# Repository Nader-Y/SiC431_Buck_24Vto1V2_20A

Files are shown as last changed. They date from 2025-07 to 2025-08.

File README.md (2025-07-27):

# SiC431 Buck Converter – 12/24 V to 1.2 V / 20 A

This project implements a high-efficiency synchronous buck converter using the Vishay SiC431 controller. It is designed to step down 12 V or 24 V input to a regulated 1.2 V output, capable of supplying up to 20 A continuous current. The design is intended for powering high-performance digital loads such as CPUs or FPGAs, with tight voltage ripple and thermal constraints.

## Specifications

 - Input Voltage: 4.5 V (min), 12 V (typ), 24 V (max)  

 - Output Voltage: 1.2 V  

 - Load Current: Up to 20 A continuous  

 - Switching Frequency: 500 kHz  

 - Output Voltage Ripple Target: ≤1%  

 - Efficiency: 88% at full load  

 - Control IC: Vishay SiC431  

 - Topology: Synchronous Buck Converter

## Intended Use

This converter is intended for high-current point-of-load applications such as:

 - Intel Xeon processor core power supply

 - FPGA and SoC internal power rails

 - Embedded computing systems requiring precise low-voltage power

## Evaluation Update

# 

Following a detailed evaluation of alternate designs, the difference in efficiency values—as discussed in the feasibility assessment—was found to be insignificant for the intended application. This conclusion is documented in: `00_Design_Calculations/Feasibility Report.doc`

## References

 - Vishay SiC431 Datasheet  

 - Intel Xeon 6 Platform Power Guidelines  

 - Capacitor vendor datasheets (Murata, Panasonic)

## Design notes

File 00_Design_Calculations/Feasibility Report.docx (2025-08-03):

# Feasibility Report: Upgrading from SiC431 (87% Efficiency) to SiC450 (95% Efficiency)

Assuming 24/7 Continuous Operation

## 1. Introduction

This report evaluates the technical and economic feasibility of upgrading a buck converter design from using the SiC431 IC (87% efficiency) to the SiC450 IC (95% efficiency). The application assumes a 1.2 V, 20 A output with continuous 24/7 operation. The analysis includes energy losses, thermal benefits, and return on investment based on IC price differences.

## 2. System and Operation Assumptions

Parameter | Value
Output voltage Vout | 1.2 V
Output current Iout | 20 A
Input voltage Vin | 12 V
Efficiency (SiC431) | 87% (0.87)
Efficiency (SiC450) | 95% (0.95)
Operation time | 24 hours/day
Operation days per year | 365 days/year
Switching frequency | 500 kHz

## 3. Power Calculations

### 3.1. Output Power

Pout=Vout⋅Iout=1.2⋅20=24 W

### 3.2. Input Power and Losses

Metric | SiC431 | SiC450
Input Power | 24/0.87≈27.59 W | 24/0.95≈25.26 W
Power Loss | 3.59 W | 1.26 W
Power Saved | — | 2.33 W less

### 3.3. Daily and Annual Energy Loss

Metric | SiC431 | SiC450
Daily Loss (Wh) | 3.59⋅24= 86.16W | 1.26⋅24=30.24
Annual Loss (Wh) | 86.16⋅365=31,436.4 | 30.24⋅365=11,037.6
Annual Loss (kWh) | 31.44 kW | 11.04 kW
Annual Energy Saved | — | 20.4 kW

### 3.4. Cost Savings (Assuming €0.30/kWh)

Annual savings per unit=20.4⋅0.30=€6.12

## 4. Thermal Considerations

- The SiC450 reduces power loss by 2.33 W.
- This can lower PCB surface temperatures, reduce cooling requirements, and potentially improve product reliability and lifespan.
- For dense or passively cooled systems, the thermal advantage may justify the upgrade independently of energy cost.

## 5. Return on Investment

Item | Value
Typical price difference (SiC450 – SiC431) | ~6.5€–2.5€
Annual energy savings | ~6.12 € per unit
Simple payback time | 7–8 months
Net gain after 1 year | ~2.12€
Net gain after 3 years | ~14.36€ (per unit)

The higher efficiency of the SiC450 becomes financially favorable in less than one year under 24/7 operation.

## 6. Summary Table

Metric | SiC431 | SiC450 | Gain (SiC450 – SiC431)
Efficiency | 87% | 95% | +8%
Input Power | 27.59 W | 25.26 W | –2.33 W
Power Loss | 3.59 W | 1.26 W | –2.33 W
Yearly Energy Waste | 31.44 kWh | 11.04 kWh | –20.4 kWh
Annual Energy Cost (at €0.30) | 9.43€ | 3.31€ | 6.12 € saved
Thermal Load | High | Lower | notable reduction
Payback Period | — | ~7-8 months | —

While the SiC450 offers higher efficiency and reduced thermal loss, it comes at a slightly higher component cost—typically around €4.00 more than the SiC431. However, under continuous 24/7 operation, the annual energy savings (~€6.12 per unit) recover this cost in approximately 7.8 months. This results in a net gain of about €2.12 after one year, and ~€14.36 after three years. Therefore, even after factoring in the IC price difference, the upgrade remains financially and technically beneficial for systems with long operating hours or thermal constraints.

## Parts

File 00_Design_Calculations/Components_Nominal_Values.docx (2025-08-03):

Design Calculations & Nominal Component Selection for Buck Converter Using SiC431

This buck converter is designed to deliver a stable and efficient 3.3 V power rail suitable for powering Intel® Xeon® processors, which require precise and reliable voltage supplies for optimal operation. The wide input voltage range from 4.5 V to 24 V allows compatibility with various power sources commonly found in server and enterprise environments where Xeon processors are deployed. Supporting a high load current of up to 20 A ensures the converter can meet the substantial power demands of multi-core Xeon CPUs during peak processing loads. The 500 kHz switching frequency balances efficiency and output ripple, aligning with the stringent voltage regulation and noise immunity requirements typical of Intel® Xeon® voltage regulator modules (VRMs), thereby ensuring processor stability, performance, and longevity in demanding applications.

### 1. Design Parameters

- VIN = 12 V
- VOUT = 1.2 V
- ETA=0.88(efficiency)
- IOUT = 20 A
- IL_(ripple) =4A (20% of IOUT)
- FSW = 500KHZ
- VCIN_P =0.5V(peak to peak input ripple)

### 2. Duty Cycle

### D=(V_(OUT))/(η⋅V_(IN))

D=1.2/(0.88⋅12)=1.2/10.56≈0.1136

### 3. Inductor Value

L=((V_(IN) -V_(OUT) )⋅D)/(ΔI_L ⋅f_(SW))

L=((12-1.2)⋅0.1136)/(0.2*20⋅500000)=(10.8⋅0.1136)/2000000≈1.2269/2000000

L ≈ 560 nH

### Ripple Current Formula:

ΔIL=((V_(in) -V_(out) )⋅D)/(L⋅f_(SW))

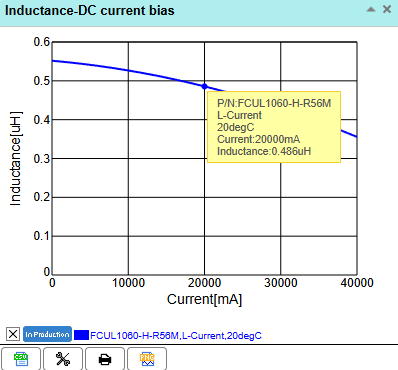
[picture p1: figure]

### Ripple Percentage:

Reducing inductance from 560 nH → 484 nH causes:

- Ripple current to increase from 3.86 A → 4.46 A
- Ripple from 19.3% → 22.3%

This is still within acceptable range, but we will:

- Need slightly more output capacitance
- See slightly higher voltage ripple
- Benefit from faster transient response

Inductor | Ripple Current (ΔIL) | % of 20 A
560 nH | 3.86 A | 19.3%
484 nH | 4.46 A | 22.3%

## Power Stage Capacitor Calculations

### 1. Output ESR Maximum Requirement

To limit the output voltage ripple within a specified value, the maximum allowable ESR of the output capacitor is determined as:

ESR_(MAX) =(V_(RIPPLE))/(I_(RIPPLE))

Where:

- V_(RIPPLE) =12 mV (Targeted≤1%of1.2 V)
- I_(RIPPLE) =3.86 A (Peak-to-peak inductor current ripple)

⇒ESR_(MAX) =(12×10^(-3))/3.86≈3.1 mΩ

This ESR requirement guides the selection of low-ESR ceramic or polymer capacitors.

### 2. Minimum Output Capacitance

The output capacitor must also handle worst-case transient response, especially when the load drops suddenly from full load to no load.

Using the energy-based formula from the SiC431 datasheet:

C_(OUT_MIN) =(L⋅(I_(OUT) +0.5⋅I_(RIPPLE) )^2)/(V_(PK)^2 -V_(OUT)^2)

Where:

- L=560 nH
- I_(OUT) =20 A
- I_(RIPPLE) =3.86 A
- V_(OUT) =1.2 V
- V_(PK) =1.25 V

C_(OUT_MIN) =(560×10^(-9) ⋅(20+0.5⋅3.86)^2)/((1.25)^2 -(1.2)^2)=(560×10^(-9) ⋅480.7)/0.1225

=0.1225560×10-9⋅480.7≈2.2mF=2200μF

This value ensures that the output capacitor can absorb inductor energy without causing output overshoot beyond safe limits.

### 3. Input Capacitance Requirement

To determine the input capacitance, we begin by calculating the RMS input current, which reaches a maximum at 50% duty cycle and minimum input voltage.

#### 3.1 Input RMS Current

I_(CIN_RMS) =I_(OUT) ⋅√(D⋅(1-D))

Where:

- I_(OUT) =20 A
- D=(V_(OUT))/(V_(IN(min)))=1.2/4.5≈0.267

I_(CIN_RMS) =20⋅√(0.267⋅(1-0.267))≈20⋅0.443=8.87 A (RMS)

This sets the thermal and ripple current specs for input capacitors.

#### 3.2 Minimum Input Capacitance

Input capacitance must be high enough to prevent input voltage ripple from exceeding acceptable levels.

C_(IN_MIN) =(I_(OUT) ⋅D⋅(1-D))/(V_(CIN(PK-PK)) ⋅f_(SW))

Where:

- V_(CIN(PK-PK)) =0.5 V(max allowed ripple)
- f_(SW) =500 kHz

C_(IN_MIN) =(20⋅0.267⋅(1-0.267))/(0.5⋅5×10^5)=3.91/250000=15.6 μF

In practice, add derating and multiple ceramic caps (X7R) to ensure low ESL and ESR. Also, electrolytic or polymer caps may be added for bulk energy storage.

## Summary Table

Parameter | Value
ESR Max (Output) | 3.1 mΩ
C_OUT Minimum | 2200 µF
I_CIN RMS | 8.87 A
C_IN Minimum | 15.6 µF

### Output Capacitor Configuration

To meet both ripple and transient load requirements, a hybrid capacitor network combining low-ESR ceramic and high-capacitance polymer capacitors is implemented at the output.

Type | Part Number | Capacitance (Each) | ESR (Each) | Qty | Total Capacitance | Effective ESR
Ceramic | Murata GRM32ER71A476KE15L | 47 µF | 2 mΩ | 3 | 141 µF | 0.67 mΩ
Polymer | Panasonic EEH-ZS1V471V | 470 µF | 11 mΩ | 4 | 1880 µF | 2.75 mΩ
Total | — | — | — | 7 | 2021 µF | ~0.58 mΩ

This configuration ensures low ESR for effective ripple suppression (well below the 3.1 mΩ limit), and sufficient total capacitance to absorb energy during rapid load release events. The total of 7 capacitors — three ceramics and four polymers — balances fast dynamic response with robust energy buffering, making the design suitable for powering demanding loads like modern CPUs or SoCs.

## 2. Harmonic and LC Filter Analysis

This section presents a detailed analysis of the harmonic content and output filter design for a 12 V to 1.2 V buck converter supplying 20 A load current. The converter operates at 500 kHz switching frequency with an efficiency of 88%, utilizing a 560 nH inductor optimized for fast transient response in point-of-load applications.

### 2.1 Power Calculations

Output power is calculated as:

Pout=Vout×Iout=1.2 V×20 A=24 W

Input power, considering efficiency η=0.88 , is:

P_(in) =(P_(out))/η=(24 W)/0.88≈27.27 W

Power loss in the converter is thus:

P_(loss) =P_(in) -P_(out) =3.27 W

### 2.2 Switch Node Harmonics

The switch node waveform is a PWM signal with amplitude 12 V and duty cycle D=0.1. The Fourier series analysis of a rectangular pulse waveform yields harmonic amplitudes as:

V_n =V_(peak) ×D×sinc(nπD)

Where: sinc(x)=(sinx)/x,and n is the harmonic number.

Calculated amplitudes for the first three harmonics are approximately:

Harmonic Order | Frequency | Approximate Amplitude
1st (Fundamental) | 500 kHz | 2.36 V
2nd | 1.0 MHz | 2.24 V
3rd | 1.5 MHz | 2.06 V

These harmonics must be attenuated by the output filter to ensure low ripple voltage and electromagnetic interference (EMI) compliance.

### 2.3 Output Filter Cutoff Frequency and Attenuation

The LC output filter cutoff frequency fc is determined by:

f_c =1/(2π√(LC))

With L=560 nH and C=100 μF:

f_c =1/(2π√(560×10^(-9) ×100×10^(-6)))≈21.3 kHz

At the switching frequency f_(sw) =500 kHz , the filter provides an attenuation of:

A_(dB) =40×log_10 ((f_(sw))/(f_c))=40×log_10 ((500 kHz)/(21.3 kHz))≈55 dB

This attenuation reduces the primary harmonic voltage from approximately 2.36 V down to less than 20 mV at the output.

### 2.5 ESR-Induced Voltage Ripple

Assuming an Equivalent Series Resistance (ESR) of 5 mΩ for the output capacitors, the ESR-related ripple voltage is:

V_(ripple) =ΔI_L ×R_(ESR) =3.86 A×5×10^(-3) Ω=19.3mV

This level of ripple is acceptable for powering digital loads at 1.2 V.

### 2.6 Practical Design Guidelines

- Capacitors: Use multiple low-ESR X7R ceramic capacitors in parallel with bulk capacitance (polymer or tantalum) to optimize transient response and stability.
- Layout: Minimize high di/dt loop areas to reduce electromagnetic noise and ringing.
- Snubbers: Implement snubber or damping circuits if oscillations or ringing are observed at the switching node.
- Measurement: Validate harmonic attenuation using FFT analysis on oscilloscope captures of the switch node and output.
- Thermal Management: Ensure adequate copper pours and via stitching under heat-generating components to dissipate approximately 3.27 W power loss efficiently.

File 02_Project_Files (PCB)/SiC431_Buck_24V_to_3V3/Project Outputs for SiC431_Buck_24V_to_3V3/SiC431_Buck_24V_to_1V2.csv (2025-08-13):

Comment | Description | Designator | Footprint | LibRef | Quantity | Manufacturer_Part_Number
100n | C0402 0.10 µF X5R 10.00% 10 V | C1 | FP-C0402-BB-MFG | CMP-03020-000918-1 | 1 | C0402C104K8PAC
330u | CAP ALUM POLY 330UF 20% 35V SMD | C2 | FP-PCR1V331MCL1GS-MFG | CMP-12462-000009-1 | 1 | PCR1V331MCL1GS
100n |  | C3, C18 | CAPC1608X95X40NL15T15 | CMP-1035-02584-2 | 2 | VJ0603Y104KXJCW1BC
47u | Chip Multilayer Ceramic Capacitors for General Purpose, 1210, 47uF, X7R, 15%, 10%, 10V | C4, C9, C10, C11, C12, C13, C14 | FP-GRM32E-0_3-0_2-IPC_A | CMP-1662-00023-3 | 7 | GRM32ER71A476KE15L
10u | Cap Ceramic 10uF 50V X7R ±10% SMD 1210 +125°C Embossed T/R | C5, C6 | FP-CL32-IPC_C | CMP-2000-06110-2 | 2 | CL32B106KBJNNNE
1u | CAP CER 1UF 50V X7R 0805 | C7, C8 | FP-CC0805-0_85-MFG | CMP-03422-000864-1 | 2 | CC0805KKX7R9BB105
4u7 | CAP CER 4.7UF 6.3V X5R 0603 | C16 | FP-CC0603-DA-MFG | CMP-03422-000495-1 | 1 | CC0603KRX5R5BB475
1u |  | C17 | CAPC1608X95X40NL15T15 | CMP-2006-00046-1 | 1 | VJ0603G105KXYCW1BC
LTST-C170KGKT | Ultra Bright AlInGaP Chip LED, 75 mW, -55 to 85 degC, 2-Pin SMD (0805), RoHS, Tape and Reel | DS1 | LTST-LTST-C170KGKT-2_V | CMP-2000-06620-1 | 1 | LTST-C170KGKT
TB005-762-02BE | Connector | J1, J2 | TB00576202BE | TB005-762-02BE | 2 | TB005-762-02BE
560n | FIXED IND | L1 | FP-FCUL1060-MFG | CMP-06042-016308-1 | 1 | FCUL1060-H-R56M=P3
3R3 |  | R1 | RESC1005X40X25LL05T10 | CMP-2002-07619-1 | 1 | RC0402FR-0733RL
562K | RES Thick Film, 562kO, 1%, 0.063W, 100ppm/°C, 0402 | R2 | FP-CRCW0402-e3-MFG | CMP-2002-00099-2 | 1 | CRCW0402562KFKED
100K |  | R3, R6 | RESC1005X40X25NL05T10 | CMP-2002-07343-1 | 2 | RC0402FR-07100KL
10K | Chip Resistor, 10 KOhm, +/- 1%, 100 mW, -55 to 155 degC, 0603 (1608 Metric), RoHS, Tape and Reel | R4, R8 | RESC1609X50X30NL8T20 | CMP-1666-00005-4 | 2 | CRCW060310K0FKEA
200K |  | R5 | RESC1005X40X25LL05T10 | CMP-2002-07497-1 | 1 | RC0402FR-07200KL
309K |  | R7 | RESC1005X40X25LL05T10 | CMP-2002-07598-1 | 1 | RC0402FR-07309KL
510R |  | R9 | RESC3116X65X40LL10T20 | CMP-2003-03988-1 | 1 | RC1206JR-07510RL
SIC431AED-T1-GE3 | SIC431AED-T1-GE3 IC Reg Buck Adj 24A MLP44-24 | U1 | FP-T22-0442-MFG | CMP-00030-87948104-1 | 1 | SIC431AED-T1-GE3

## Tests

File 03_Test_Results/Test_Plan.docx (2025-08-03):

## Test Plan for 12 V to 1.2 V, 20 A Buck Converter

### 1. Objectives

- Verify that the converter meets electrical specifications (voltage, current, ripple, efficiency).
- Validate transient response under dynamic load.
- Assess stability (control loop behavior).
- Ensure thermal performance is within limits.
- Evaluate EMI performance.

### 2. Test Equipment

Equipment | Purpose
Oscilloscope (≥100 MHz BW) | Ripple, switching waveform, transient tests
Current probe (≥20 A) | Measure inductor/load current
Differential voltage probe | Accurate Vout measurement under load
Power analyzer / DMM | Efficiency, Vin, Iin, Vout, Iout
Programmable load (≥20 A) | Static & dynamic load testing
Electronic power supply (12 V) | Vin source
Thermal camera or IR sensor | Thermal evaluation
Spectrum analyzer (up to 100 MHz or more) | EMI/FFT analysis of switch node

### 3. Test Procedures

### 3.1 Functional Tests

Test | Method / Acceptance Criteria
Startup Test | Power on from 0 to 12 V. Output must rise smoothly to 1.2 V.
No Load Output Voltage | Measure Vout at 0 A: must be 1.2 V ±2%.
Full Load Output Voltage | At 20 A: Vout must remain within ±3% of 1.2 V.
Switching Frequency | Confirm ~500 kHz using scope on switch node.
Duty Cycle Check | Duty cycle should ≈ 10% at 1.2 V out.

### 3.2 Performance Tests

Test | Method / Target
Efficiency | Measure Vin, Iin, Vout, Iout. Efficiency = Vout × Iout / Vin × Iin. Target: ~88%.
Output Ripple (Vpp) | Measure ripple on Vout at full load with scope, AC-coupled, at 20 MHz BW. Target: ≤25 mVpp.
Inductor Current Ripple | Scope current probe on inductor. Should match ~3.86 App.

### 3.3 Transient Tests

Test | Method / Acceptance Criteria
Load Step: 0 A to 10 A | Step load, measure undershoot and recovery time.
Load Step: 10 A to 20 A | Same as above. Undershoot < 100 mV, recovery < 100 µs.
Fast Transient Load Test | 100 ns–1 µs load steps using electronic load.

### 3.4 Stability (Control Loop)

Test | Method
Bode Plot (optional) | Use frequency injection (e.g. AP300) to measure phase margin. Aim for ≥45° phase margin, gain margin ≥10 dB.
Step Response | Observe Vout with fast load step. No ringing or instability.

### 3.5 Thermal Evaluation

Test | Method / Criteria
Steady-State Thermal | Run at full load for 10+ minutes. Use IR camera. Max IC temperature < 125 °C (check datasheet).
Hot Spot Identification | Find and document components >85 °C at 25 °C ambient.

### 3.6 EMI / Harmonics

Test | Method / Target
Switch Node FFT | Use scope FFT on switch node. Peaks should match harmonic predictions (~2.36 V, 2.24 V...).
Conducted EMI | If pre-compliance test setup is available (LISN, EMI filter), evaluate conducted emissions against CISPR 25/Class B.

### 4. Test Conditions

- Input Voltage: 12 V ±10%
- Output Current Range: 0 A to 20 A
- Ambient Temperature: 25 °C ±5 °C
- Load Type: Resistive or programmable electronic load
- Capacitor ESR: 5 mΩ assumed
- Cooling: Natural convection unless otherwise specified

### 5. Pass/Fail Criteria

Parameter | Criteria
Vout Regulation | ±2% at no load, ±3% at full load
Ripple Voltage | ≤25 mVpp
Efficiency | ≥87% target
Thermal | <125 °C device max
EMI (optional) | Below CISPR/EN threshold

### Optional Enhancements

- Line Transient Test: Sweep Vin from 10.8 V to 13.2 V and observe Vout response.
- Short-Circuit Test: Test response to short-circuit at output (if IC supports protection).
- Cold Start Test: Test startup at -20 °C or 0 °C ambient.

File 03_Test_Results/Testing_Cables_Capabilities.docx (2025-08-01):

## Required Cable Capabilities for Testing 12 V to 1.2 V / 20 A Buck Converter

Cable Type | Use | Required Capability / Specs
Input Power Cables | Connect 12 V lab supply | 🔹 Minimum 20 A continuous current 🔹 Voltage rating ≥ 30 V 🔹 Low resistance (<5 mΩ/m) 🔹 Insulation temp ≥ 80 °C
Output Load Cables | Deliver 1.2 V / 20 A to load | 🔹 Support high current with low voltage drop 🔹 Length < 30 cm if possible 🔹 Use 10–12 AWG 🔹 Parallel runs OK
Ground Sense Cable | Remote sense at load ground | 🔹 Thin, shielded cable okay 🔹 Must be twisted with V+ sense line 🔹 Ideally differential input at measurement point
Voltage Sense Cable | Remote sense at 1.2 V rail | 🔹 Shielded pair (for noise immunity) 🔹 Thin (22–26 AWG is fine) 🔹 Directly connected at load pins
Oscilloscope Probes / Clips | For Vout, SW node, ripple | 🔹 Use low-inductance ground spring probes 🔹 Differential probes for precision Vout readings
Current Probe Cable / Loop | Measure Iin, Iout | 🔹 Must handle up to 20 A AC/DC 🔹 Suitable for large loop size if needed 🔹 Shielded against EMI
Thermocouple / IR Probe Cable | Thermal testing | 🔹 Must support >100 °C measurement 🔹 Electrically isolated tip preferred
EMI/FFT Injection Cable | For harmonic/EMI testing | 🔹 Coaxial (SMA/BNC) 🔹 Shielded twisted pair if using LISN 🔹 Matched impedance (50 Ω) for spectrum analyzers
Banana / Binding Post Cables | Power input/output | 🔹 Rated ≥ 20 A 🔹 Gold-plated preferred for repeatability 🔹 Secure connection at all terminals
Sense Compensator / Loop Injection Cables | Loop testing | 🔹 Coaxial or twisted pair 🔹 Shielded for low noise 🔹 Injection transformer compatible (if using AP300 or similar)

## Practical Tips

- Prefer flexible silicone-insulated cables (rated to 105 °C or more) to avoid stiffness and heat buildup.
- Color code cables clearly (e.g., red = VIN, black = GND, blue = Vout Sense).
- Twisted pairs for all low-level signals to reduce coupling noise.
- For EMI testing, coaxial and measurement cables are short, grounded, and follow proper probe de-embedding techniques.

## Suggested Cable Types

Use Case | Suggested Cable Spec
High current (VIN/VOUT) | 10–12 AWG silicone wire, rated 600 V / 30 A
Low-current signals | 22–26 AWG twisted pair (e.g., Cat5 wire)
Probe extensions | RG-174 coaxial or equivalent
Scope ground loops | Tektronix ground spring or mini loop

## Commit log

2025-07-27 Last local milestone pushed to remote
    [PCB2.PcbDoc, Sheet1.SchDoc, SiC431_Buck_24V_to_3V3.PrjPcb]
2025-07-27 V1 schematic polished
    [Sheet1.SchDoc, SiC431_Buck_24V_to_3V3.PrjPcb]
2025-07-28 V2 schematic (Annotated + Netlabeled), Layout
    [PCB2.PcbDoc, Sheet1.SchDoc]
2025-08-01 Add harmonic and LC filter analysis for 12V-to-1.2V, 20A buck converter. Include power and ripple calculations, test plan, and cabling/coupling guidelines for high-current operation.
    [PCB2.PcbDoc, Sheet1.SchDoc, SiC431_Buck_24V_to_3V3.PrjPcb]
2025-08-02 Selected and placed VIN and output capacitors; documented power stage capacitor calculations.
    [PCB2.PcbDoc, Sheet1.SchDoc, SiC431_Buck_24V_to_3V3.PrjPcb]
2025-08-03 Further Schematic review, Added BOM approx 27 Euro
    [PCB2.PcbDoc, Sheet1.SchDoc, SiC431_Buck_24V_to_3V3.PrjPcb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]
2025-08-05 Changing from molex_0393800102(2.2Euro) To TB005-762-02BE(0.66Euro) same design parameters maintained + added SIC431 Evaluation Board UserManual
    [PCB2.PcbDoc, Sheet1.SchDoc]
2025-08-13 Added Layout V2 + Stack up
    [PCB2.PcbDoc, Sheet1.SchDoc, SiC431_Buck_24V_to_1V2.csv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]
